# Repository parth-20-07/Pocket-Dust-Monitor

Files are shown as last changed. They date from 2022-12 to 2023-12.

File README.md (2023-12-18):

# Pocket Air Quality Index Monitor

## Why AQI Monitor is needed?
Carry Air Pocket Monitor before stepping out of your house in order to know the quality of the air you’re breathing. The pocket-sized air monitoring device is handy and easy to carry around.

It helps you understand the level of Particulate Matter 2.5 of your location. Works as both – real-time indoor and outdoor air quality monitoring sensor; the LCD display shows you PM reading indicating if the air is safe or not.

Having a desktop friendly version helps to determine the quality of air which can help you improving your life and work quality.

<br>

## Features of our AQI Monitor
- Shows the value of PM2.5 along with the safety level.
- Shows simultaneous value of PM1.0, PM2.5 and PM10.
- Plots the graph of PM2.5 on a graph in difference of 5 minutes.
- Approx. 1.5 hours Battery Backup.
- Type C charging support.

<br>

## How to assemble the project
1. Download the latest version of firmware from the /Firmware folder
2. Edit the Firmware as per the requirement with the help of guide provided in /Firmware/README.md
3. Order the components from the Bill of Materials as per the requirement.
4. Make the Hardware circuit
   1.  Solder them on General Purpose PCB Board using the design below (or)
   2.  Order the PCB by providing the PCB Developer with the gerber file available in /Hardware/PCB_Gerber.zip and solder all the component on it
5.  Upload the firmware on the the hardware

<br>

## How to use the device
1. Press the push button to turn on the device.
2. The device will start with a bootup screen with the company logo.
3. The landing page will show the value of PM 2.5 of screen.
4. Press the change screen button to switch between pages. The device works in 3 modes:
   1. Live PM 2.5 data screen.
   2. Live PM 1.0, PM 2.5, PM 10 data screen.
   3. PM 2.5 graph screen which plots the value of PM 2.5 in bar graph at an interval of 5 mins.

<center>

## Schematic Design
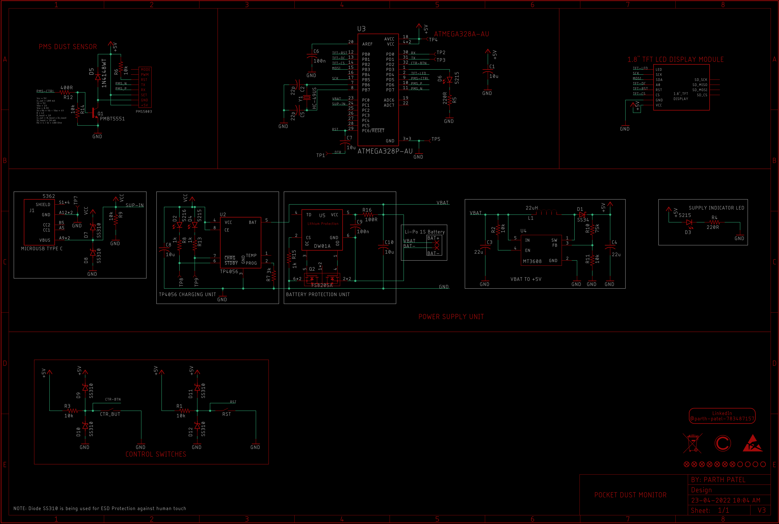
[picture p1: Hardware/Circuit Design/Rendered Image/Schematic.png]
Circuit Schematic

<br><br>

## PCB Design

Top View

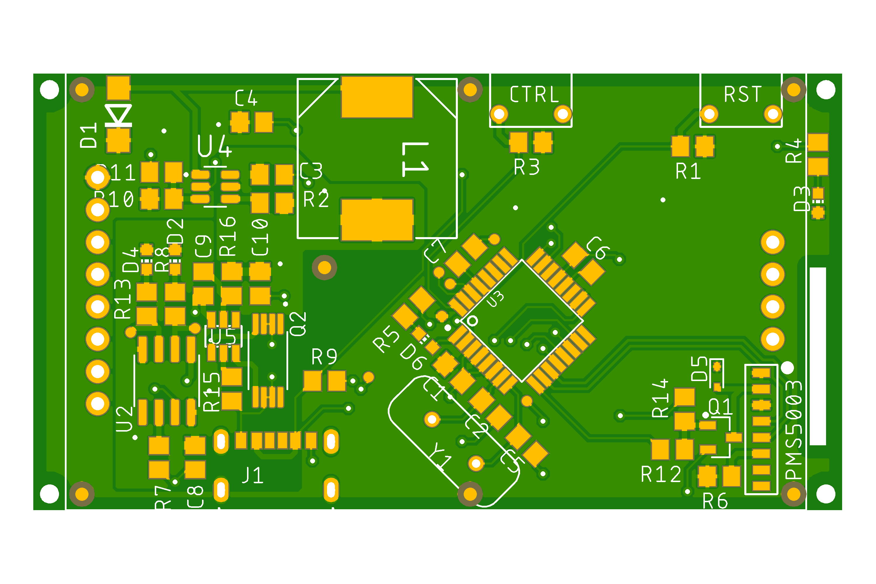
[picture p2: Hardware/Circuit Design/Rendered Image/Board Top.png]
Board Top Design


Bottom View

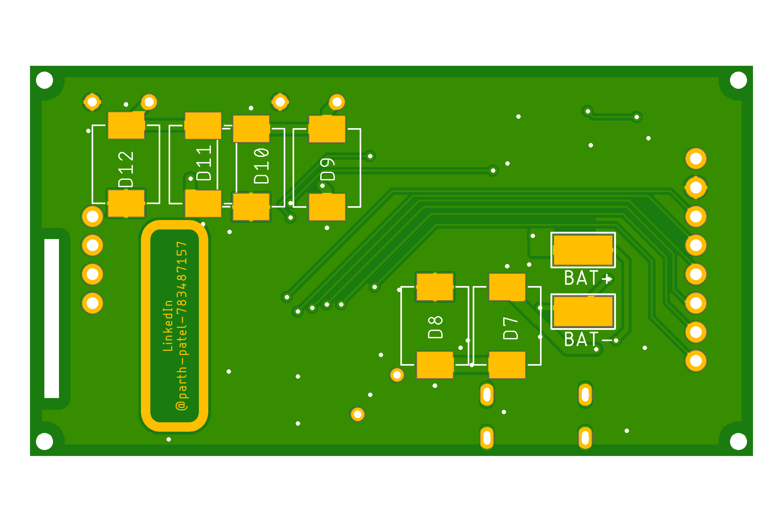
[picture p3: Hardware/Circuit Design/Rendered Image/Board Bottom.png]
Board Bottom Design


## Rendered Images

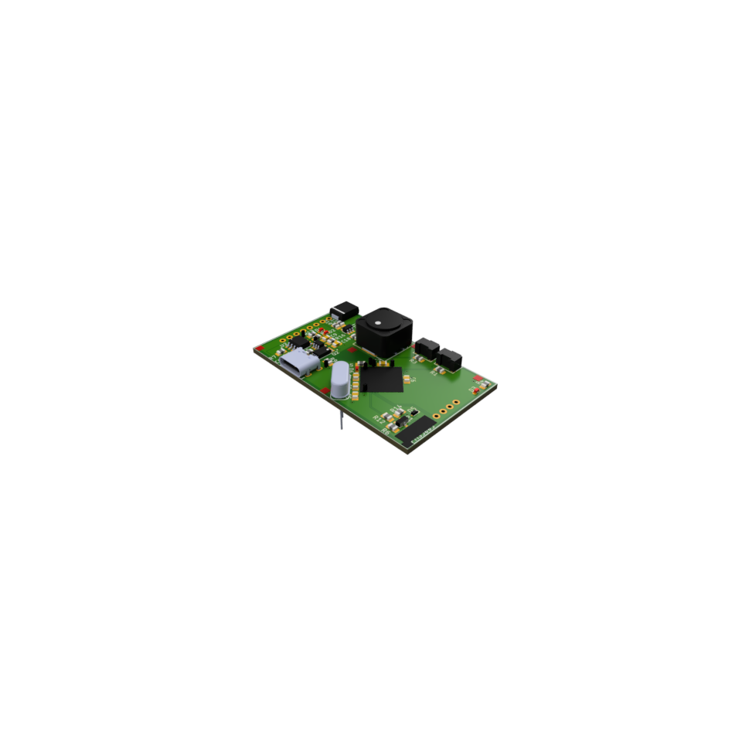
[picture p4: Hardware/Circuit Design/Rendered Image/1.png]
Rendered Design 1

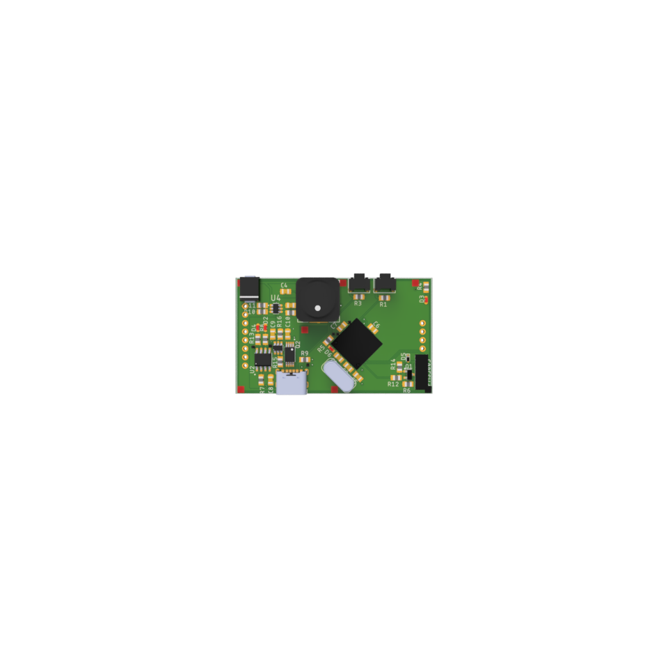
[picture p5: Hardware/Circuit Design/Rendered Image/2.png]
Rendered Design 2

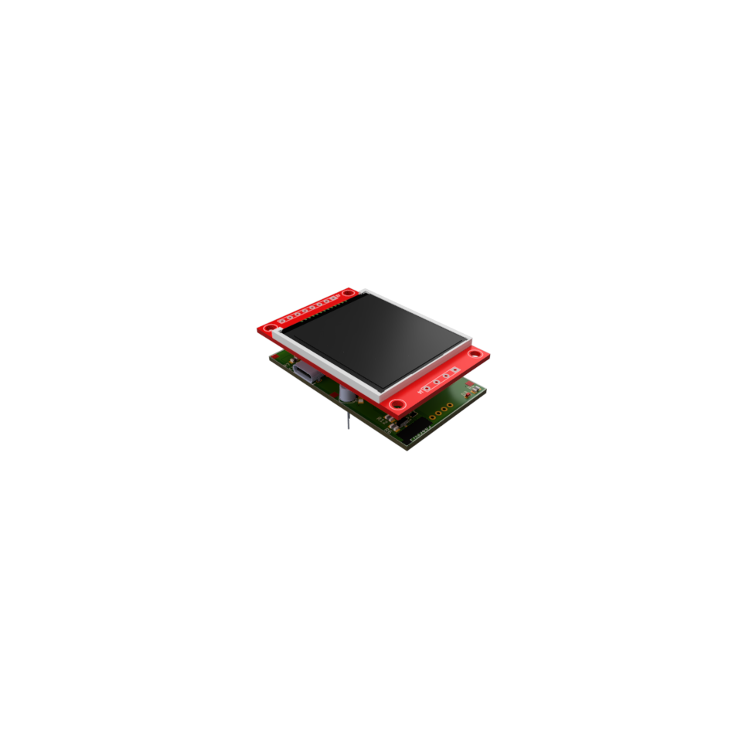
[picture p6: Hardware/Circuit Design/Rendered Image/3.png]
Rendered Design 3

</center>

## Tools Used
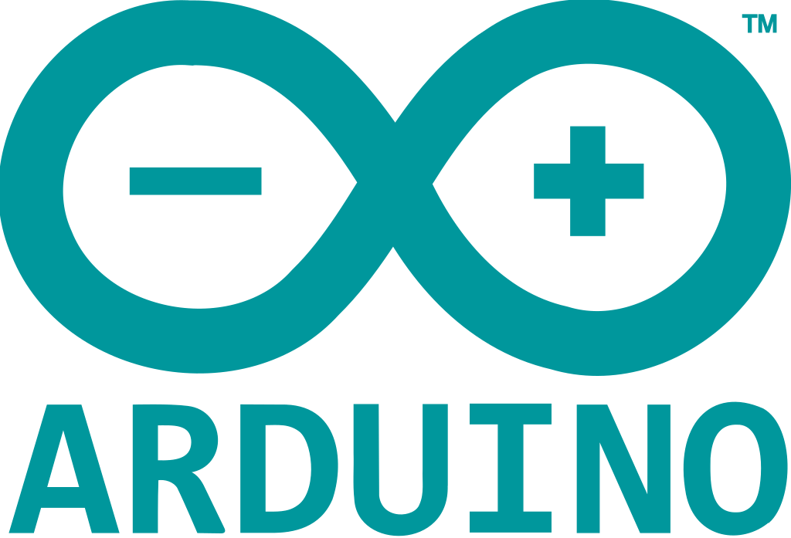
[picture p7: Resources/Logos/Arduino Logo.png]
Arduino

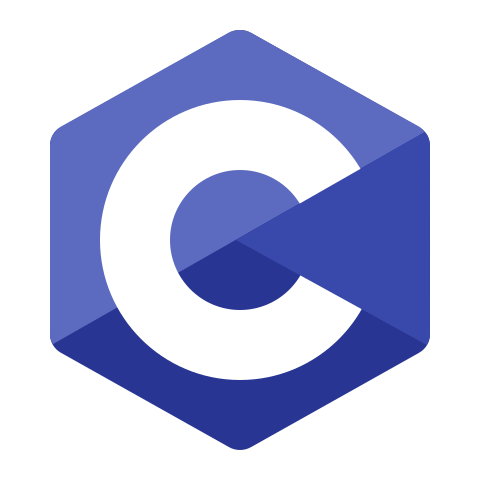
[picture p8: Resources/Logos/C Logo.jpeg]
C

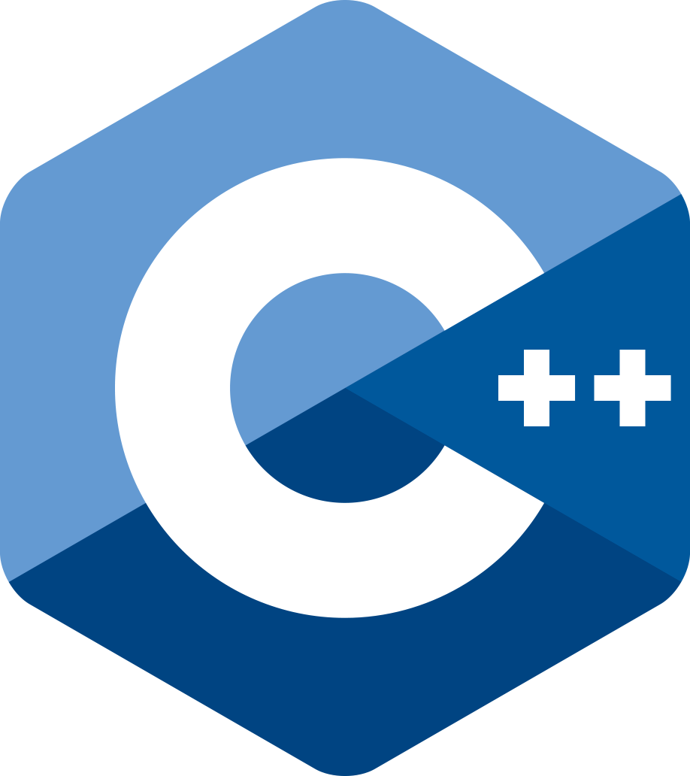
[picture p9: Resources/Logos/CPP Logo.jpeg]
CPP

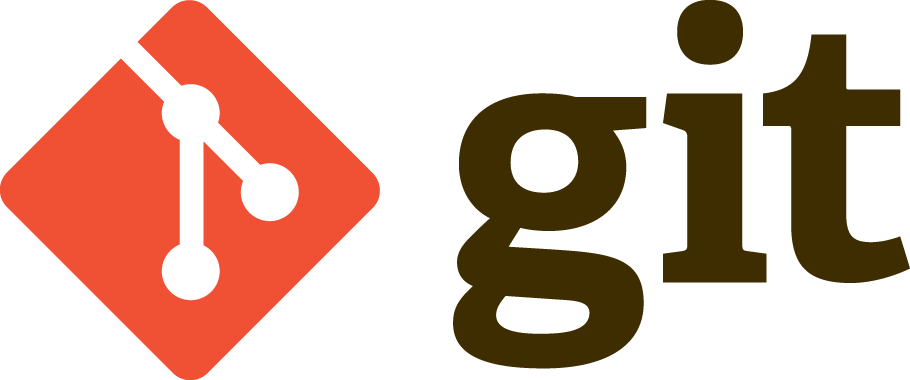
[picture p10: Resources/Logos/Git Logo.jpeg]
Git

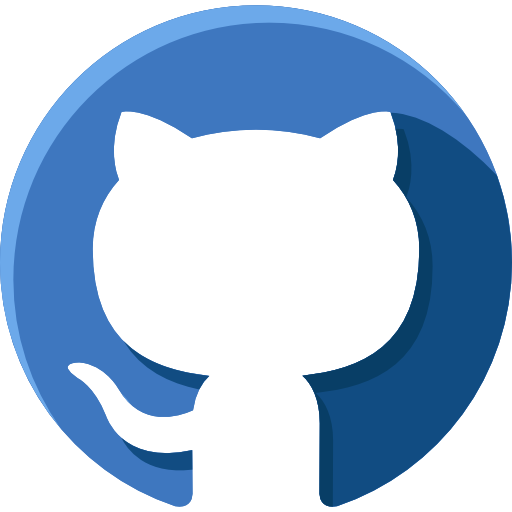
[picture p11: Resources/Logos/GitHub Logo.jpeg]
GitHub

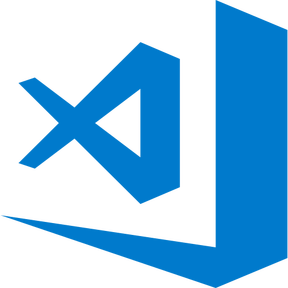
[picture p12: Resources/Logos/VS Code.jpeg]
VS Code

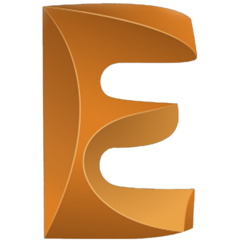
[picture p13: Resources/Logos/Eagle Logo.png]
Eagle

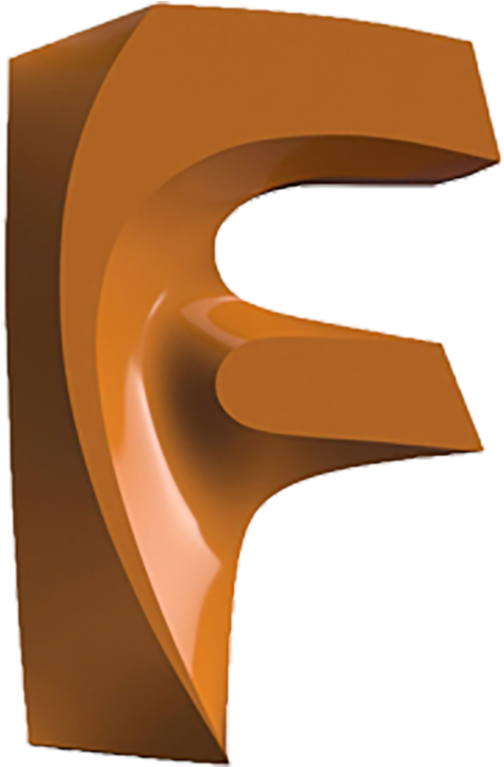
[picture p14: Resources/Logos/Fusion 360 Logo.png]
Fusion 360


<br><br>

## Design Details
- Designed for: Ecologic Pvt. Ltd.
- Designed by: [Parth Patel](mailto:parth.pmech@gmail.com)

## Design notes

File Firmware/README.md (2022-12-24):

# Firmware V2.0

### Configuration Guide for the device firmware

<br>
Modify the <Device_Configuration.h> file in the following method.

1. Under the "Sensor Connected" tab, uncomment the type of sensor connected to the device.
2. Under the "Display Connected" tab, uncomment the type of display connected.
3. If SD Support is required, uncomment the "#define SD_SUPPORT_ENABLED" under "SD Card Connected" tab.

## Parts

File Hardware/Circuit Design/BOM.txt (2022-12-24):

Partlist exported from D:/Backup Files/Files/Items/Internship/7. Ecologic/Ecologic Projects/Pocket Dust Monitor/Hardware/Circuit Design/Design.sch at 23-04-2022 01:57 PM

Qty Value           Device                    Package                     Parts                                    Description                                                                                                       AVAILABILITY BOM     DESCRIPTION                                                                                          MF                           MP                          PACKAGE                        POPULARITY PRICE PURCHASE-URL                                                   SPICEPREFIX                                                       
1   1.8"_TFT        1.8"_TFT                  1.8"_TFT                    DISPLAY                                                                                                                                                                                                                                                                                                                                                                                                                                                                                                                        
1   100R            R-US_R0805                R0805                       R16                                      RESISTOR, American symbol                                                                                                                                                                                                                                                                                                           85                                                                              R                                                                 
2   100n            C-USC0805                 C0805                       C6, C9                                   CAPACITOR, American symbol                                                                                                                                                                                                                                                                                                          63                                                                              C                                                                 
7   10k             R-US_R0805                R0805                       R1, R2, R3, R6, R9, R11, R14             RESISTOR, American symbol                                                                                                                                                                                                                                                                                                           85                                                                              R                                                                 
4   10u             C-USC0805                 C0805                       C1, C7, C8, C10                          CAPACITOR, American symbol                                                                                                                                                                                                                                                                                                          63                                                                              C                                                                 
1   1N4148WT        1N4148WT                  SODFL1608X70N               D5                                       Diode Switching 100V 0.125A 2-Pin SOD-523 Check availability                                                                                                                                                                                                                                                                                                                                                                                                                          
3   1k              R-US_R0805                R0805                       R8, R13, R15                             RESISTOR, American symbol                                                                                                                                                                                                                                                                                                           85                                                                              R                                                                 
2   220R            R-US_R0805                R0805                       R4, R5                                   RESISTOR, American symbol                                                                                                                                                                                                                                                                                                           85                                                                              R                                                                 
2   22p             C-USC0805                 C0805                       C2, C5                                   CAPACITOR, American symbol                                                                                                                                                                                                                                                                                                          63                                                                              C                                                                 
2   22u             C-USC0805                 C0805                       C3, C4                                   CAPACITOR, American symbol                                                                                                                                                                                                                                                                                                          63                                                                              C                                                                 
1   22uH            DR127-221-R               INDM125125X800N             L1                                       POWER INDUCTOR Check availability                                                                                 In Stock              Inductor Power Shielded Drum Core 221.5uH/220uH 20% 100KHz Ferrite 1.29A 376mOhm DCR T/R            Eaton                        DR127-221-R                 Nonstandard Eaton                         None  https://pricing.snapeda.com/search/part/DR127-221-R/?ref=eda                                                                     
1   3k              R-US_R0805                R0805                       R7                                       RESISTOR, American symbol                                                                                                                                                                                                                                                                                                           85                                                                              R                                                                 
1   400R            R-US_R0805                R0805                       R12                                      RESISTOR, American symbol                                                                                                                                                                                                                                                                                                           85                                                                              R                                                                 
3   5215            LEDCHIP-LED0603           CHIP-LED0603                D3, D4, D6                               LED                                                                                                                                                                                                                                                                                                                                 26                                                                                                                                                
1   5216            LEDCHIP-LED0603           CHIP-LED0603                D2                                       LED                                                                                                                                                                                                                                                                                                                                 26                                                                                                                                                
1   5362            6_PIN_TYPE_C_FEMALE       GCT_USB4125-GF-A-0190_REVA2 J1                                       Check availability                                                                                                In Stock              USB-C (USB TYPE-C) USB 2.0 Receptacle Connector 24 (6+18 Dummy) Position Surface Mount, Right Angle  Through Hole                Global Connector Technology USB4125-GF-A-0190              None             None                                                           https://pricing.snapeda.com/search/part/USB4125-GF-A-0190/?ref=eda
2   7058            DIP_3X6MM_SIDE_PRESS_2PIN DIP_3X6MM_SIDE_PRESS_2PIN   CTR_BUT, RST                                                                                                                                                                                                                                                                                                                                                                                                                                                                                                                   
1   75k             R-US_R0805                R0805                       R10                                      RESISTOR, American symbol                                                                                                                                                                                                                                                                                                           85                                                                              R                                                                 
1   ATMEGA328P-AU   ATMEGA328P-AU             QFP80P900X900X120-32N       U3                                       ATmega Series 20 MHz 32 KB Flash 2 KB SRAM 8-Bit Microcontroller - TQFP-32 Check availability                     In Stock              AVR AVR® ATmega Microcontroller IC 8-Bit 20MHz 32KB (16K x 16) FLASH 32-TQFP (7x7)                  Microchip Technology         ATMEGA328P-AU               TQFP-32 Microchip                         None  https://pricing.snapeda.com/search/part/ATMEGA328P-AU/?ref=eda                                                                   
1   DW01A           DW01A                     SOT23-6                     U5                                       Check availability                                                                                                Not in stock          One Cell Lithium-ion/Polymer Battery Protection IC                                                  Fortune Semiconductor        DW01A                       SOT-23-6 Fortune Semiconductor            None                                                                                                                                   
1   FS8205A         FS8205A                   SOP65P640X120-8N            Q2                                       N/A Check availability                                                                                            Not in stock                                                                                                              Fortune Semiconductor        FS8205A                     Package                                   None                                                                                                                                   
1   HC-49US         ECS-160-20-4X             XTAL_ECS-160-20-4X          Y1                                       CRYSTAL T/H Check availability                                                                                    In Stock              16 MHz ±30ppm Crystal 20pF 40 Ohms HC-49/US                                                         ECS Inc.                     ECS-160-20-4X               HC-49US ECS Inc.                          None  https://pricing.snapeda.com/search/part/ECS-160-20-4X/?ref=eda                                                                   
1   MT3608          MT3608                    SOT95P280X145-6N            U4                                       High Efficiency 1.2MHz 2A Step Up Converter Check availability                                                    Not in stock          High Efficiency 1.2MHz 2A Step Up Converter                                                         Aerosemi Technology Co., Ltd MT3608                      Package                                   None                                                                                                                                   
1   PMBT5551        PMBT5551                  SOT95P240X110-3N            Q1                                       AAL Eindhoven MK                                                                                                                                                                                                                                                                                                                                                                                                                                                                      
1   PMS5003         PMS5003                   PMS5003                     PMS5003                                                                                                                                                                                                                                                                                                                                                                                                                                                                                                                        
6   SS310           SS310                     DIOM6859X262N               D7, D8, D9, D10, D11, D12                Check availability                                                                                                In Stock              3A, 100V, Schottky Rectifier                                                                        Taiwan Semiconductor         SS310                       SMC-2 Taiwan Semiconductor                None  https://pricing.snapeda.com/search/part/SS310/?ref=eda                                                                           
1   SS34            SS34                      DO214                       D1                                       SS34 Schottky diode                                                                                               In Stock              Diode Schottky 40 V 3A Surface Mount SMC (DO-214AB)                                                 ON Semiconductor             SS34                        SMC-2 ON Semiconductor                    None  https://pricing.snapeda.com/search/part/SS34/?ref=eda                                                                            
1   TP4056          TP4056                    SOP127P600X175-9N           U2                                       Complete single cell Li-Ion battery with a constant current / constant voltage linear charger  Check availability Not in stock          Complete single cell Li-Ion battery with a constant current / constant voltage linear charger       NanJing Top Power ASIC Corp. TP4056                      None                                      None

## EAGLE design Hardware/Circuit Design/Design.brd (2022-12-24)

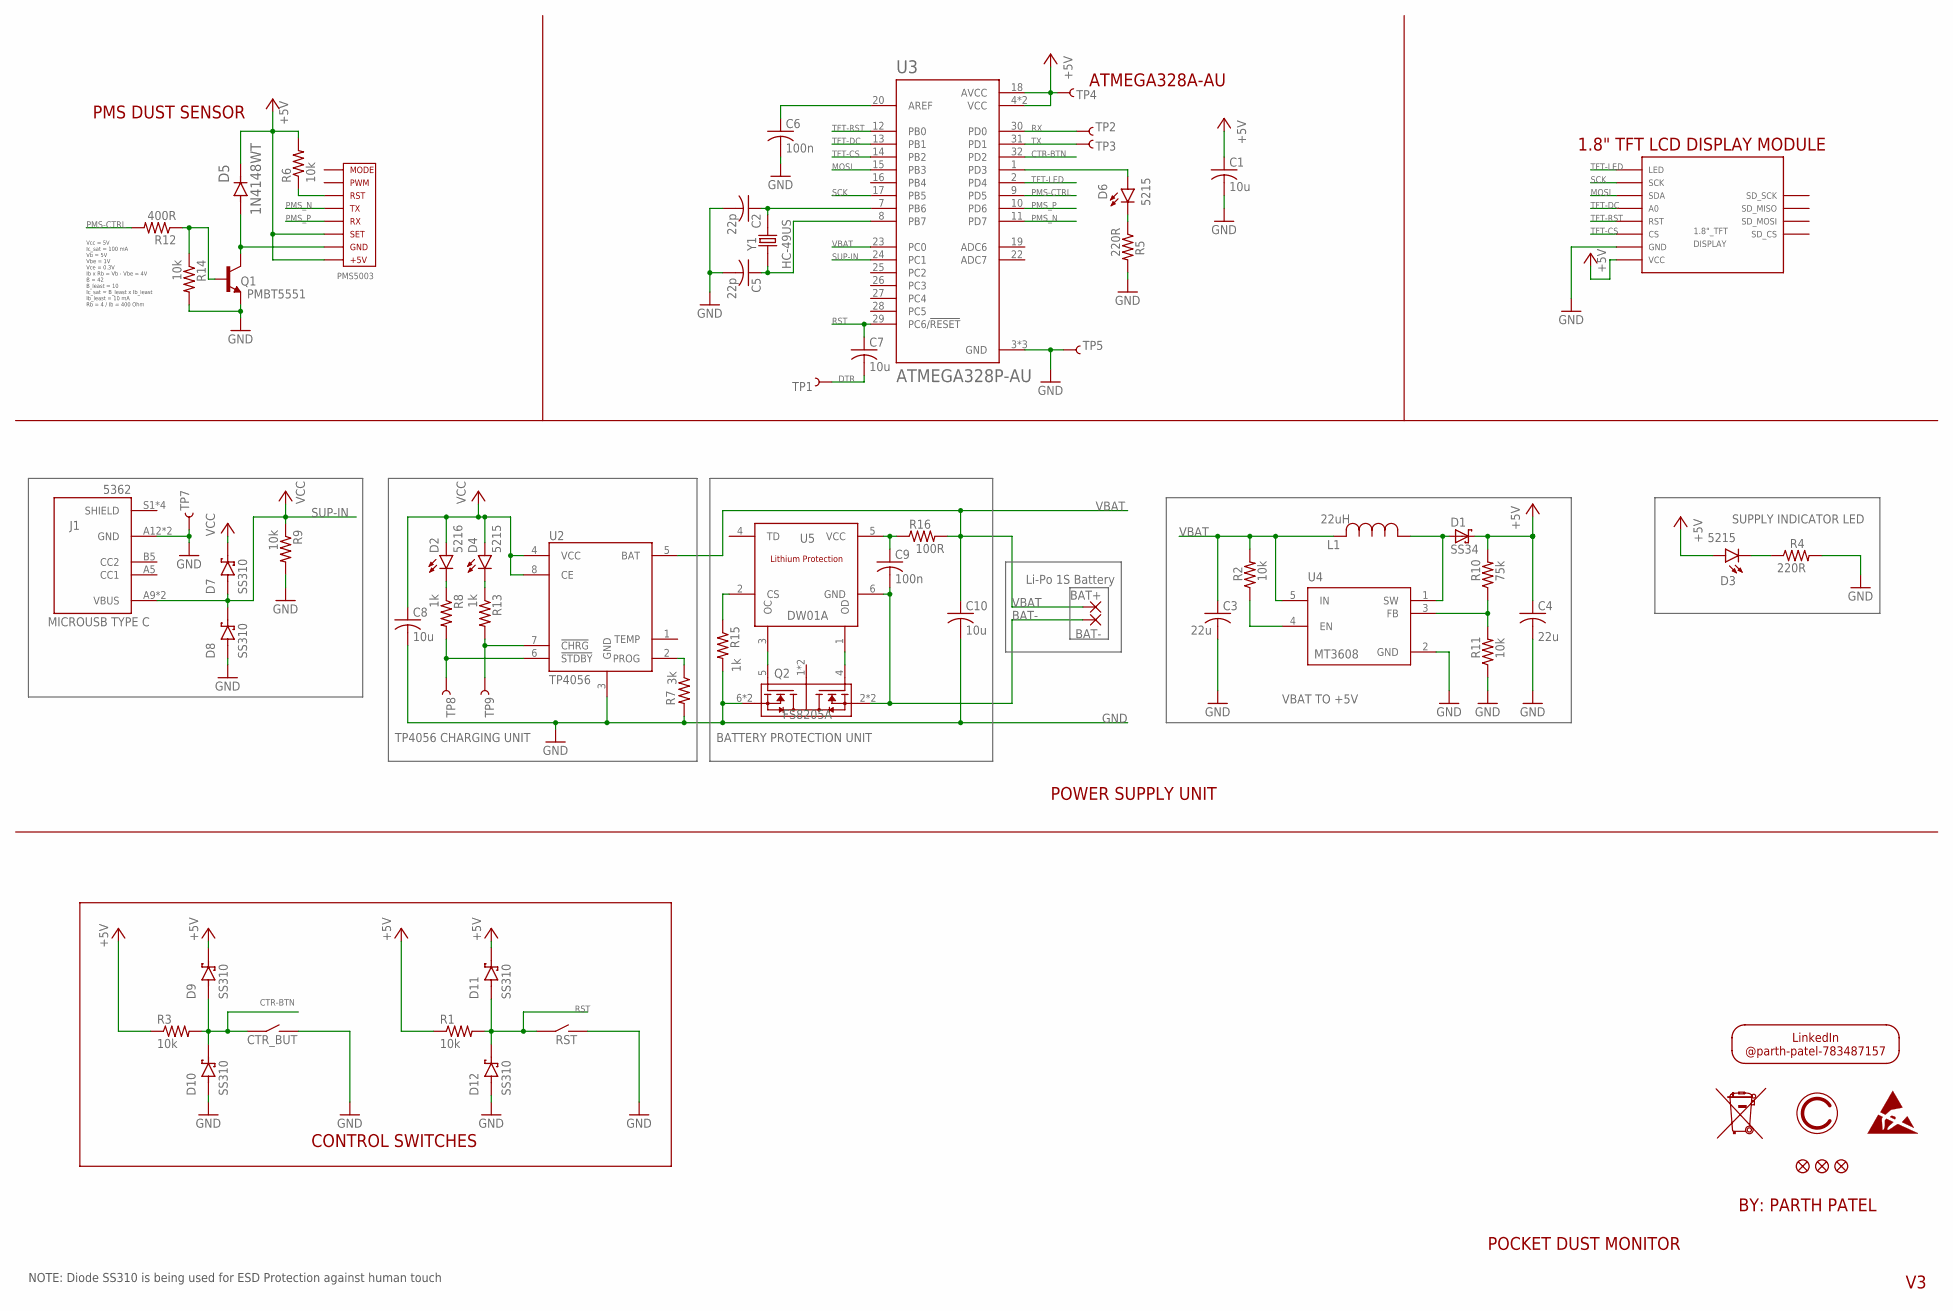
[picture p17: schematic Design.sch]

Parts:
BAT+: WIREPADSMD5-2,5; 5-2,5
BAT-: WIREPADSMD5-2,5; 5-2,5
C1, C7, C8, C10: 10u; C0805
C2, C5: 22p; C0805
C3, C4: 22u; C0805
C6, C9: 100n; C0805
CTR_BUT: 7058; DIP_3X6MM_SIDE_PRESS_2PIN
D1: SS34; DO214
D2: 5216; CHIP-LED0603
D3, D4, D6: 5215; CHIP-LED0603
D5: 1N4148WT; SODFL1608X70N
D7, D8, D9, D10, D11, D12: SS310; DIOM6859X262N
DISPLAY: 1.8"_TFT
FID3, FID4, FID5: FIDUCIAL""; FIDUCIAL_1MM
J1: 5362; GCT_USB4125-GF-A-0190_REVA2
L1: 22uH; INDM125125X800N
PMS5003: PMS5003
Q1: PMBT5551; SOT95P240X110-3N
Q2: FS8205A; SOP65P640X120-8N
R1, R2, R3, R6, R9, R11, R14: 10k; R0805
R4, R5: 220R; R0805
R7: 3k; R0805
R8, R13, R15: 1k; R0805
R10: 75k; R0805
R12: 400R; R0805
R16: 100R; R0805
RST: 7058; DIP_3X6MM_SIDE_PRESS_2PIN
TP1, TP2, TP3, TP4, TP5, TP7: TEST-POINT3; PAD.03X.03
TP8: ~STDBY; PAD.03X.03
TP9: ~CHRG; PAD.03X.03
U2: TP4056; SOP127P600X175-9N
U3: ATMEGA328P-AU; QFP80P900X900X120-32N
U4: MT3608; SOT95P280X145-6N
U5: DW01A; SOT23-6
U$1: LOGO_17MM; FOOTPRINT_17MM
Y1: HC-49US; XTAL_ECS-160-20-4X

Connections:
+5V: C1.1, C4.1, D1.C, D3.A, D5.D+, D9.C (K), D11.C (K), DISPLAY.VCC (+5V), PMS5003.+5V, PMS5003.SET, R1.1, R3.1, R6.2, R10.2, TP4.P$1, U3.4 (VCC), U3.6 (VCC), U3.18 (AVCC)
BAT-: BAT-.1, C9.2, Q2.2 (S1), Q2.3 (S1), U5.6 (GND)
CTR-BTN: CTR_BUT.P$1 (S1), D9.A, D10.C (K), R3.2, U3.32 (PD2)
DTR: C7.2, TP1.P$1
GND: C1.2, C2.2, C3.2, C4.2, C5.2, C6.2, C8.2, C10.2, CTR_BUT.P$2 (S2), D8.A, D10.A, D12.A, DISPLAY.GND, J1.A12 (GND), J1.B12 (GND), Q1.E, Q2.6 (S2), Q2.7 (S2), R4.2, R5.2, R7.2, R9.2, R11.1, R14.2, R15.2, RST.P$2 (S2), TP5.P$1, TP7.P$1, U2.3 (GND), U3.3 (GND), U3.5 (GND), U3.21 (GND), U4.2 (GND)
MOSI: DISPLAY.SDA, U3.15 (PB3)
unnamed: D5.D-, PMS5003.GND, Q1.C
unnamed: C5.1, U3.8 (PB7), Y1.1
unnamed: D3.C, R4.1
unnamed: Q1.B, R12.1, R14.1
unnamed: R2.1, U4.4 (EN)
unnamed: C6.1, U3.20 (AREF)
unnamed: PMS5003.RST, R6.1
unnamed: D4.C, R13.1
unnamed: D2.C, R8.1
unnamed: C2.1, U3.7 (PB6), Y1.2
unnamed: D1.A, L1.1, U4.1 (SW)
unnamed: R10.1, R11.2, U4.3 (FB)
unnamed: D6.C, R5.1
unnamed: D6.A, U3.1 (PD3)
unnamed: Q2.5 (G2), U5.3 (OC)
unnamed: R13.2, TP9.P$1, U2.7 (!CHRG)
unnamed: R8.2, TP8.P$1, U2.6 (!STDBY)
unnamed: R7.1, U2.2 (PROG)
unnamed: Q2.4 (G1), U5.1 (OD)
unnamed: R15.1, U5.2 (CS)
unnamed: C9.1, R16.1, U5.5 (VCC)
PMS-CTRL: R12.2, U3.9 (PD5)
PMS_N: PMS5003.TX, U3.11 (PD7)
PMS_P: PMS5003.RX, U3.10 (PD6)
RST: C7.1, D11.A, D12.C (K), R1.2, RST.P$1 (S1), U3.29 (PC6/!RESET)
RX: TP2.P$1, U3.30 (PD0)
SCK: DISPLAY.SCK, U3.17 (PB5)
SUP-IN: D7.A, D8.C (K), J1.A9 (VBUS), J1.B9 (VBUS), R9.1, U3.24 (PC1)
TFT-CS: DISPLAY.CS, U3.14 (PB2)
TFT-DC: DISPLAY.DC (A0), U3.13 (PB1)
TFT-LED: DISPLAY.LED, U3.2 (PD4)
TFT-RST: DISPLAY.RST, U3.12 (PB0)
TX: TP3.P$1, U3.31 (PD1)
VBAT: BAT+.1, C3.1, C10.1, L1.2, R2.2, R16.2, U2.5 (BAT), U3.23 (PC0), U4.5 (IN)
VCC: C8.1, D2.A, D4.A, D7.C (K), U2.4 (VCC), U2.8 (CE)

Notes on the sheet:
POWER SUPPLY UNIT
POCKET DUST MONITOR
BY: PARTH PATEL
CONTROL SWITCHES
PMS DUST SENSOR
PMS5003
ATMEGA328A-AU
1.8" TFT LCD DISPLAY MODULE
MICROUSB TYPE C
VBAT TO +5V
TP4056 CHARGING UNIT
Vcc = 5V Ic_sat = 100 mA Vb = 5V Vbe = 1V Vce = 0.3V Ib x Rb = Vb - Vbe = 4V B = 42 B_least = 10 Ic_sat = B_least x Ib_least Ib_least = 10 mA Rb = 4 / Ib = 400 Ohm
Li-Po 1S Battery
BATTERY PROTECTION UNIT
SUPPLY INDICATOR LED
NOTE: Diode SS310 is being used for ESD Protection against human touch

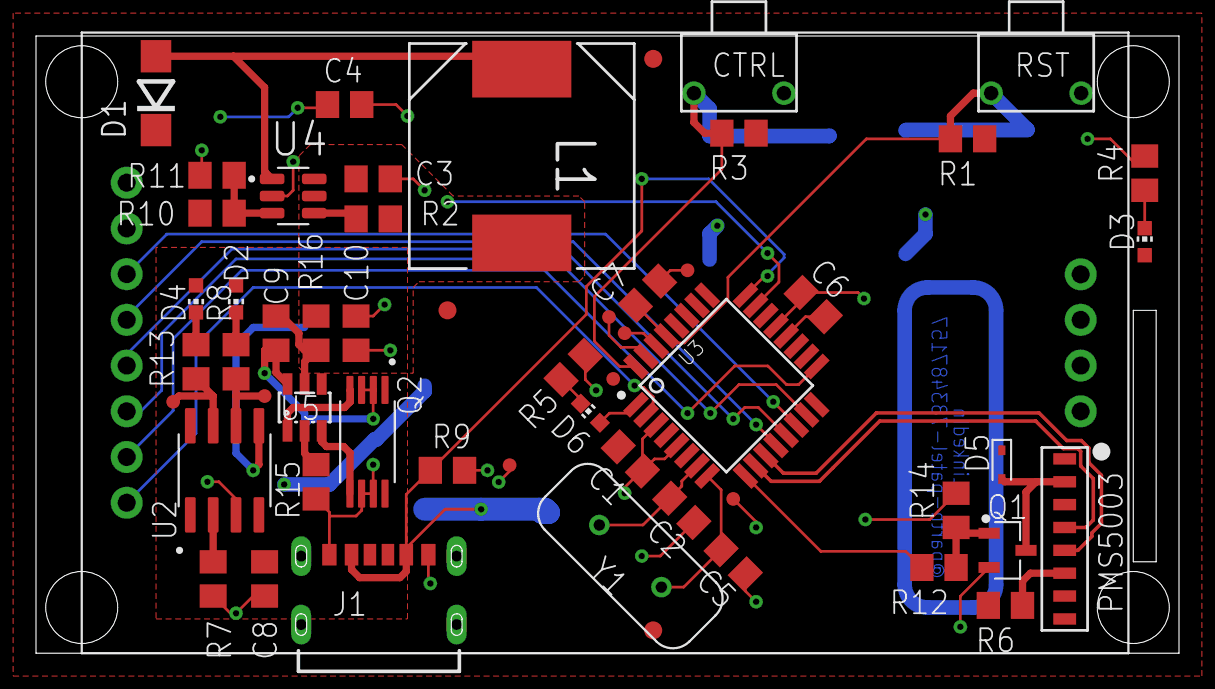
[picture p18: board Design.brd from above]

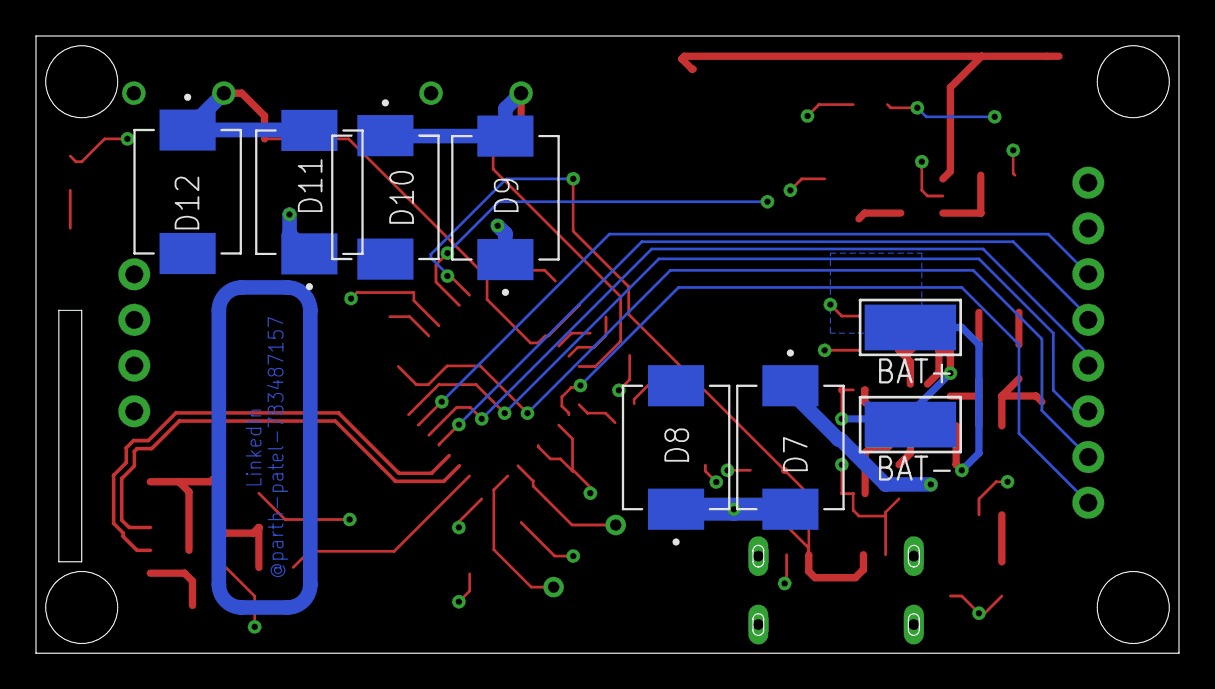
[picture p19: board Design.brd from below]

Board: 2 copper layers, 63.5 x 34.3 mm, 65 parts (9 on the bottom side), 41 nets.

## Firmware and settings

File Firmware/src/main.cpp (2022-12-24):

/**
 * @file main.cpp
 * @author Parth Patel (parth.pmech@gmail.com)
 * @brief
 * @version 0.1
 * @date 2021-12-05
 * @copyright Copyright (c) 2021
 * ! DO NOT CHANGE
 */

//!=============================== BASIC DECLARATION ===============================//
#include <Arduino.h>
#include "Pin_Connection.h"
#include "Variable_Declaration.h"
#include "Sensor_Data_Collection.cpp"
#include <avr/sleep.h>
//!==================================================================================//

//!============================== FUNCTION DEFINITION ==============================//
void boot_screen(void);
void graphic_data_screen(void);
void drawing_battery(void);
void three_point_data_screen(void);
void draw_graph_screen(void);
void plot_graph_bar(void);
void changing_screen_display(void);
void change_screen(void);
void start_device_peripherals(void);
void shutdown_device_peripherals(void);
//!==================================================================================//

//!============================== FUNCTION DECLARATION ==============================//

/**
 * @brief Print the Boot Screen on the device startup
 */
void boot_screen(void)
{
  Serial.println("Printing Boot Screen");
  Serial.println("Drawing LOGO");
  screen.background(BLACK_COLOR);
  screen.setTextSize(2);
  screen.stroke(WHITE_COLOR);
  screen.text("ECOLOGIC", 20, (screen_height / 2) - 10);
  delay(5000);
}

/**
 * @brief Draws the bubble screen for displaying the PM 2.5 Value on the screen
 */
void graphic_data_screen(void)
{
  changing_screen_display();
  change_screen_flag = false;
  Serial.println("Drawing Graphic Screen");
  uint16_t registered_level = 0;
  collect_dust_quality_data();
  screen.background(BLACK_COLOR);
  // Design variable declaration
  double indicator_height = 4;
  double indicator_bar_width = screen_width - 4;
  double green_indicator = (MAX_SAFETY_LIMIT * indicator_bar_width) / MAX_HAZARDOUS_LIMIT;
  double warning_indicator = ((MAX_WARNING_LIMIT - MAX_SAFETY_LIMIT) * indicator_bar_width) / MAX_HAZARDOUS_LIMIT;
  double severe_indicator = ((MAX_UNHEALTHY_LIMIT - MAX_WARNING_LIMIT) * indicator_bar_width) / MAX_HAZARDOUS_LIMIT;
  double danger_indicator = ((MAX_HAZARDOUS_LIMIT - MAX_UNHEALTHY_LIMIT) * indicator_bar_width) / MAX_HAZARDOUS_LIMIT;
  uint8_t indicator_x_starting_pos = 2;
  uint8_t indicator_y_starting_pos = (screen_height / 2) + 32;
  uint8_t green_indicator_height = (uint8_t)green_indicator;
  uint8_t warning_indicator_height = (uint8_t)warning_indicator;
  uint8_t severe_indicator_height = (uint8_t)severe_indicator;
  uint8_t danger_indicator_height = (uint8_t)danger_indicator;
  uint8_t seperation_line_height = 25;

  // Drawing seperation line
  screen.stroke(GREY_COLOR);
  screen.line(0, seperation_line_height, (screen_width / 2) - 30, seperation_line_height);
  screen.setTextSize(1);
  screen.text("PM2.5", (screen_width / 2) - 10, seperation_line_height - 3);
  screen.line((screen_width / 2) + 30, seperation_line_height, screen_width, seperation_line_height);

  // Drawing the indicator Bar
  screen.stroke(GREEN_COLOR);
  screen.fill(GREEN_COLOR);
  screen.rect(indicator_x_starting_pos, indicator_y_starting_pos, green_indicator_height, indicator_height);
  screen.stroke(YELLOW_COLOR);
  screen.fill(YELLOW_COLOR);
  screen.rect(indicator_x_starting_pos + green_indicator_height, indicator_y_starting_pos, warning_indicator_height, indicator_height);
  screen.stroke(ORANGE_COLOR);
  screen.fill(ORANGE_COLOR);
  screen.rect(indicator_x_starting_pos + green_indicator_height + warning_indicator_height, indicator_y_starting_pos, severe_indicator_height, indicator_height);
  screen.stroke(RED_COLOR);
  screen.fill(RED_COLOR);
  screen.rect(indicator_x_starting_pos + green_indicator_height + warning_indicator_height + severe_indicator_height, indicator_y_starting_pos, danger_indicator_height, indicator_height);
  last_millis = millis();
  bool first_time = true;
  while (1)
  {
    if ((digitalRead(INT_PIN) == LOW) || change_screen_flag)
    {
      change_screen();
      break;
    }

    // Calculating values for the design
    int arrow_x_position = 0;
    if (registered_level < MAX_HAZARDOUS_LIMIT)
      arrow_x_position = indicator_x_starting_pos + (registered_level * indicator_bar_width / MAX_HAZARDOUS_LIMIT);
    else
      arrow_x_position = indicator_x_starting_pos + indicator_bar_width;
    int arrow_y_position = indicator_y_starting_pos - 5;

    if (((registered_level > 0) && ((millis() - last_millis) > SCREEN_REFRESH_TIME)) || (first_time))
    {
      Serial.println("Registered Level: " + (String)registered_level);
      first_time = false;
      drawing_battery(); // Drawing Header: Company Name and Battery Percentage
      screen.noStroke();

      // Clearing the older values
      screen.stroke(BLACK_COLOR);
      screen.fill(BLACK_COLOR);
      screen.rect(0, arrow_y_position - 9, screen_width, 10);
      screen.rect(0, indicator_y_starting_pos + indicator_height + 5, screen_width, 15);

      // Drawing The circle with latest values
      if (registered_level < MAX_SAFETY_LIMIT)
      {
        screen.stroke(GREEN_COLOR);
        screen.fill(GREEN_COLOR);
        screen.text("SAFE", indicator_x_starting_pos, indicator_y_starting_pos + indicator_height + 5);
      }
      else if (registered_level < MAX_WARNING_LIMIT)
      {
        screen.stroke(YELLOW_COLOR);
        screen.fill(YELLOW_COLOR);
        screen.text("MODERATE", indicator_x_starting_pos, indicator_y_starting_pos + indicator_height + 5);
      }
      else if (registered_level < MAX_UNHEALTHY_LIMIT)
      {
        screen.stroke(ORANGE_COLOR);
        screen.fill(ORANGE_COLOR);
        screen.text("UNHEALTHY", indicator_x_starting_pos, indicator_y_starting_pos + indicator_height + 5);
      }
      else
      {
        screen.stroke(RED_COLOR);
        screen.fill(RED_COLOR);
        screen.text("HAZARDOUS", indicator_x_starting_pos, indicator_y_starting_pos + indicator_height + 5);
      }
      screen.circle(screen_width / 2, (screen_height / 2) - 15, screen_width / 4);

      // Draw the indicator arrow
      screen.line(arrow_x_position, arrow_y_position, arrow_x_position - 4, arrow_y_position - 8);
      screen.line(arrow_x_position, arrow_y_position, arrow_x_position + 4, arrow_y_position - 8);
      screen.line(arrow_x_position - 4, arrow_y_position - 8, arrow_x_position + 4, arrow_y_position - 8);

      // Writing the text on the circle
      screen.setTextSize(3);
      screen.stroke(BLACK_COLOR);
      screen.text(pm_ae_2_5, (screen_width / 2) - 20, (screen_height / 2) - 25);
      screen.setTextSize(1);
      screen.text("ug/m", (screen_width / 2) - 10, (screen_height / 2) + 5);
      screen.text("3", (screen_width / 2) + 13, (screen_height / 2) + 2);
      last_millis = millis();
    }
    collect_dust_quality_data();
    registered_level = atoi(pm_ae_2_5);
  }
}

/**
 * @brief Draws the battery level after measuring the battery level on the screen in upper right corner of screen when called.
 */
void drawing_battery(void)
{
  // Writing Company Logo
  screen.stroke(WHITE_COLOR);
  screen.setTextSize(2);
  screen.text(company_name, 2, MARGIN_BUFFER);

  int xStart = screen_width - BATTERY_SYMBOL_WIDTH - MARGIN_BUFFER;
  int yStart = MARGIN_BUFFER;
  // Clearing previous battery value
  screen.noStroke();
  screen.fill(BLACK_COLOR);
  screen.rect(xStart, yStart, BATTERY_SYMBOL_WIDTH, BATTERY_SYMBOL_HEIGHT);
  // Creating battery Outline
  screen.stroke(WHITE_COLOR);
  screen.rect(xStart, yStart, BATTERY_SYMBOL_WIDTH, BATTERY_SYMBOL_HEIGHT);
  screen.fill(WHITE_COLOR);
  screen.rect(xStart + BATTERY_SYMBOL_WIDTH, yStart + MARGIN_BUFFER, MARGIN_BUFFER, (BATTERY_SYMBOL_HEIGHT - (2 * MARGIN_BUFFER)));

  // Creating Battery Fill
  float val1 = (analogRead(BATTERY_INPUT) - MIN_BATTERY_ADC_VALUE);
  float available_battery_percentage = (val1 * 100) / MAX_BATTERY_ADC_VALUE;
  // Serial.println("Raw Battery Analog value:" + (String)analogRead(BATTERY_INPUT));
  Serial.println("Battery Level: " + (String)available_battery_percentage + "%");
  float bat_bar_width = (available_battery_percentage * BATTERY_SYMBOL_WIDTH) / 100;
  int battery_bar_width = bat_bar_width;
  // Serial.println("Integer Bar Width:" + (String)battery_bar_width);
  screen.noStroke();

  if (available_battery_percentage < LOW_BATTERY_PERCENT)
    screen.fill(RED_COLOR);
  else if (available_battery_percentage < MEDIUM_BATTERY_PERCENT)
    screen.fill(ORANGE_COLOR);
  else
    screen.fill(GREEN_COLOR);
  screen.rect(xStart + 1, yStart + 1, battery_bar_width - 2, BATTERY_SYMBOL_HEIGHT - 2);
  if (digitalRead(CONNECTED_SUPPLY_PIN))
  {
    Serial.println("Charger Connected");
    int batxStart = screen_width - (BATTERY_SYMBOL_WIDTH / 2) - MARGIN_BUFFER;
    int batyStart = MARGIN_BUFFER + 1;
    int bat_symbol_width = 2;
    screen.stroke(WHITE_COLOR);
    screen.line(batxStart, batyStart, batxStart - bat_symbol_width, batyStart + (BATTERY_SYMBOL_HEIGHT / 2));
    screen.line(batxStart - bat_symbol_width, batyStart + (BATTERY_SYMBOL_HEIGHT / 2) - 1, batxStart + bat_symbol_width, batyStart + (BATTERY_SYMBOL_HEIGHT / 2) - 1);
    screen.line(batxStart + bat_symbol_width, batyStart + (BATTERY_SYMBOL_HEIGHT / 2) - 1, batxStart, batyStart + BATTERY_SYMBOL_HEIGHT - 2);
    screen.line(batxStart, batyStart + BATTERY_SYMBOL_HEIGHT - 2, batxStart, batyStart);
  }
}

/**
 * @brief Draws the screen and the values of PMS 1.0, PM 2.5 and PM 10.0 together on a single screen in a grid manner
 */
void three_point_data_screen(void)
{
  changing_screen_display();
  change_screen_flag = false;
  Serial.println("Drawing 3 Data Monitor Screen");
  collect_dust_quality_data();

  screen.background(BLACK_COLOR);

  // Drawing the layout
  drawing_battery();
  int seperation_line_height = 25;
  screen.stroke(GREY_COLOR);
  screen.line(0, seperation_line_height, screen_width, seperation_line_height);
  screen.line(screen_width / 2, seperation_line_height, screen_width / 2, screen_height);
  screen.line(screen_width / 2, (screen_height + seperation_line_height) / 2, screen_width, (screen_height + seperation_line_height) / 2);
  screen.stroke(ORANGE_COLOR);
  screen.setTextSize(1);
  screen.text("PM1.0", (3 * screen_width / 4) - 10, seperation_line_height + 5);
  screen.text("PM10", (3 * screen_width / 4) - 10, ((screen_height + seperation_line_height) / 2) + 5);
  screen.text("ug/m", (screen_width / 4) - 15, screen_height - 10);
  screen.text("3", (screen_width / 4) + 10, screen_height - 15);
  screen.setTextSize(2);
  screen.text("PM2.5", (screen_width / 4) - 27, seperation_line_height + 5);
  int text_seperation_height = 45;

  // Writing the data
  bool first_time = true;
  last_millis = millis();
  Serial.println("Starting Unit");
  while (1)
  {
    if ((digitalRead(INT_PIN) == LOW) || change_screen_flag)
    {
      change_screen();
      break;
    }

    while (((millis() - last_millis) > SCREEN_REFRESH_TIME) || (first_time))
    {
      first_time = false;

      if (atoi(pm_ae_1_0) > 0)
      {
        Serial.println("PM AE 1.0: " + String(atoi(pm_ae_1_0)));
        Serial.println("PM AE 2.5: " + String(atoi(pm_ae_2_5)));
        Serial.println("PM AE 10: " + String(atoi(pm_ae_10_0)));
        Serial.println();
        drawing_battery();
        // Cleaning Previous Values
        screen.noStroke();
        screen.fill(BLACK_COLOR);
        screen.rect((screen_width / 4) - 30, text_seperation_height + 25, 60, 30);
        screen.rect((3 * screen_width / 4) - 25, ((screen_height + text_seperation_height) / 2) + 5, 60, 30);
        screen.rect((3 * screen_width / 4) - 25, text_seperation_height - 5, 60, 30);

        // Writing New Values
        screen.setTextSize(3);
        screen.stroke(YELLOW_COLOR);
        screen.text(pm_ae_2_5, (screen_width / 4) - 25, text_seperation_height + 30);
        screen.text(pm_ae_10_0, (3 * screen_width / 4) - 20, ((screen_height + text_seperation_height) / 2) + 10);
        screen.stroke(PINK_COLOR);
        screen.text(pm_ae_1_0, (3 * screen_width / 4) - 20, text_seperation_height);
        last_millis = millis();
      }
      Serial.println();
      collect_dust_quality_data();
    }
  }
}

/**
 * @brief Draws the background to plot the values of PM 2.5
 */
void draw_graph_screen(void)
{
  Serial.println("Draw Graph Background");
  collect_dust_quality_data();

  screen.background(BLACK_COLOR);
  screen.stroke(GREY_COLOR);
  screen.line(GRAPH_BUFFER_SCREEN, GRAPH_BUFFER_SCREEN, GRAPH_BUFFER_SCREEN, screen_height - GRAPH_BUFFER_SCREEN);
  screen.line(GRAPH_BUFFER_SCREEN, screen_height - GRAPH_BUFFER_SCREEN, screen_width - GRAPH_BUFFER_SCREEN, screen_height - GRAPH_BUFFER_SCREEN);
  int x_dots = ((screen_width - (2 * GRAPH_BUFFER_SCREEN)) / GRAPH_BUFFER_SCREEN + 1);
  int y_dots = ((screen_height - (2 * GRAPH_BUFFER_SCREEN)) / GRAPH_BUFFER_SCREEN) + 1;
  for (size_t i = 0; i < y_dots; i++)
    for (size_t j = 0; j < x_dots; j++)
      screen.point((j * GRAPH_BUFFER_SCREEN) + GRAPH_BUFFER_SCREEN, (i * GRAPH_BUFFER_SCREEN) + GRAPH_BUFFER_SCREEN);

  screen.stroke(WHITE_COLOR);
  screen.setTextSize(1);
  screen.text("PM2.5", screen_width - 40, 10);
  screen.text("50 divs", 1, 1);
  screen.text("5 mins", screen_width - 40, screen_height - 10);
  for (size_t i = 0; i < (y_dots / 2) + 1; i++)
    screen.line(GRAPH_BUFFER_SCREEN, screen_height - (2 * i * GRAPH_BUFFER_SCREEN) - GRAPH_BUFFER_SCREEN, GRAPH_BUFFER_SCREEN / 2, screen_height - (2 * i * GRAPH_BUFFER_SCREEN) - GRAPH_BUFFER_SCREEN);
  for (size_t i = 0; i < (x_dots / 2); i++)
    screen.line((2 * i * GRAPH_BUFFER_SCREEN) + GRAPH_BUFFER_SCREEN, screen_height - GRAPH_BUFFER_SCREEN, (2 * i * GRAPH_BUFFER_SCREEN) + GRAPH_BUFFER_SCREEN, screen_height - (GRAPH_BUFFER_SCREEN / 2));
}

/**
 * @brief Plots the graph bars corresponding to value of PM 2.5 after drawing the graph background
 */
void plot_graph_bar(void)
{
  draw_graph_screen();
  change_screen_flag = false;
  Serial.println("Plot Graph");
  last_millis = millis();
  int x_levels = ((screen_width - (2 * GRAPH_BUFFER_SCREEN)) / GRAPH_BUFFER_SCREEN) / 2;
  int y_levels = ((screen_height - (2 * GRAPH_BUFFER_SCREEN)) / (GRAPH_BUFFER_SCREEN * 2));
  int last_graph_position = 0;
  uint16_t registered_level = 0;
  float graph_divisions = 100;
  float scaling_factor = screen_height / (y_levels * graph_divisions);
  screen.stroke(BLACK_COLOR);

  int x_last_pos, y_last_pos;

  while (last_graph_position <= x_levels)
  {
    if (last_graph_position == x_levels)
    {
      draw_graph_screen();
      last_graph_position = 0;
    }

    if ((digitalRead(INT_PIN) == LOW) || change_screen_flag)
    {
      change_screen();
      break;
    }

    registered_level = 0;
    collect_dust_quality_data();
    registered_level = atoi(pm_ae_2_5);

    if ((((millis() - last_millis) > GRAPH_PLOT_TIME) || (last_graph_position == 0)) && (registered_level > 10))
    {
      Serial.println("PM AE 2.5: " + (String)registered_level);
      // Calculating Bar Values
      int scaled_value = 0;
      int height = 0;
      if (registered_level < MAX_HAZARDOUS_LIMIT)
      {
        scaled_value = registered_level * scaling_factor;
        height = scaled_value;
      }
      else
      {
        scaled_value = screen_height - (2 * GRAPH_BUFFER_SCREEN);
        height = screen_height - (2 * GRAPH_BUFFER_SCREEN);
      }
      int x_pos = GRAPH_BUFFER_SCREEN + (2 * GRAPH_BUFFER_SCREEN * last_graph_position) + 1;
      int y_pos = screen_height - GRAPH_BUFFER_SCREEN - scaled_value;
      int width = (2 * GRAPH_BUFFER_SCREEN) - 1;

      if (registered_level < MAX_SAFETY_LIMIT)
        screen.fill(GREEN_COLOR);
      else if (registered_level < MAX_WARNING_LIMIT)
        screen.fill(YELLOW_COLOR);
      else if (registered_level < MAX_UNHEALTHY_LIMIT)
        screen.fill(ORANGE_COLOR);
      else
        screen.fill(RED_COLOR);
      screen.stroke(BLACK_COLOR);
      screen.rect(x_pos, y_pos, width, height);

      if (last_graph_position == 0)
      {
        x_last_pos = x_pos + (width / 2);
        y_last_pos = y_pos;
      }
      else
      {
        x_pos = x_pos + (width / 2);
        screen.fill(WHITE_COLOR);
        screen.stroke(WHITE_COLOR);
        screen.circle(x_last_pos, y_last_pos, 2);
        screen.circle(x_pos, y_pos, 2);
        screen.line(x_last_pos, y_last_pos, x_pos, y_pos);
        x_last_pos = x_pos;
        y_last_pos = y_pos;
      }

      last_millis = millis();
      last_graph_position++;
    }
  }
}

void put_device_to_sleep(void)
{
  Serial.println("Entering Sleep mode");
  screen.fill(GREY_COLOR);
  screen.rect(10, (screen_height / 2) - 40, screen_width - 20, 80);
  screen.fill(BLACK_COLOR);
  screen.stroke(BLACK_COLOR);
  screen.setTextSize(1);
  screen.text("SHUTTING DOWN", 30, (screen_height / 2));
  delay(2000);
  boot_screen();
  screen_counter = 0;
  change_screen_flag = false;
  shutdown_device_peripherals();
  cli();
  set_sleep_mode(SLEEP_MODE_PWR_DOWN);
  cli();
  sleep_enable();
  cli();
  Serial.println("Placing Device in sleep mode");
  Serial.flush();
  delay(2000);
  cli();
  attachInterrupt(digitalPinToInterrupt(INT_PIN), change_screen, LOW);
  cli();
  interrupts();
  sleep_cpu();
}

void changing_screen_display(void)
{
  screen.fill(GREY_COLOR);
  screen.rect(10, (screen_height / 2) - 40, screen_width - 20, 80);
  screen.fill(BLACK_COLOR);
  screen.stroke(BLACK_COLOR);
  screen.setTextSize(1);
  screen.text("CHANGING SCREEN", 20, (screen_height / 2));
}

void change_screen(void)
{
  sleep_disable();
  detachInterrupt(digitalPinToInterrupt(INT_PIN));
  Serial.println("Button pressed");
  delay(500);

  change_screen_flag = true;
  uint64_t sleep_timer = millis();
  while (digitalRead(INT_PIN) == LOW)
    if ((millis() - sleep_timer) > 2000)
    {
      screen_counter = 4;
      return;
    }

  if (screen_counter < 3)
    screen_counter++;
  else
    screen_counter = 1;
  return;
}

void start_device_peripherals(void)
{
  Serial.println("Starting Device Peripherals");
  digitalWrite(PMS_CTRL, HIGH);
  digitalWrite(TFT_DISPLAY_LED, HIGH);
  screen.begin();
  screen.setRotation(180);
  screen_height = screen.height();
  screen_width = screen.width();
  screen.background(BLACK_COLOR);
  screen.stroke(WHITE_COLOR);
  boot_screen();
}

void shutdown_device_peripherals(void)
{
  digitalWrite(PMS_CTRL, LOW);
  digitalWrite(TFT_DISPLAY_LED, LOW);
  Serial.println("Stopping Device Peripherals");
}

//!==================================================================================//

void setup()
{
  Serial.begin(9600);
  Serial.println("\n\n\n----------------------------------------------------------------------------------------");
  Serial.println("Starting Device");
  setup_sensors();
  setup_peripheral_pin_mode();
  start_device_peripherals();
  Serial.println("Setup Done");
  start_device_peripherals();
}

void loop()
{
  changing_screen_display();
  switch (screen_counter)
  {
  case 1:
    Serial.println("\n----------------------------------------------------------------------------------------");
    graphic_data_screen();
    break;

  case 2:
    Serial.println("\n----------------------------------------------------------------------------------------");
    three_point_data_screen();
    break;

  case 3:
    Serial.println("\n----------------------------------------------------------------------------------------");
    plot_graph_bar();
    break;

  case 4:
    Serial.println("\n----------------------------------------------------------------------------------------");
    put_device_to_sleep();
    break;
  }
}

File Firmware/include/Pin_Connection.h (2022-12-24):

/**
 * @file PIN_CONNECTION.h
 * @author Parth Patel (parth.pmech@gmail.com)
 * @brief Check the Pin Connection on this page as per the connection
 * @version 0.1
 * @date 2021-12-27
 * @copyright Copyright (c) 2021
 * ! DO NOT CHANGE
 */

#ifndef PIN_CONNECTION_H
#define PIN_CONNECTION_H

// GPIO PINS
#define NANO_GPIO_2 2
#define NANO_GPIO_3 3
#define NANO_GPIO_4 4
#define NANO_GPIO_5 5
#define NANO_GPIO_6 6
#define NANO_GPIO_7 7
#define NANO_GPIO_8 8
#define NANO_GPIO_9 9
#define NANO_GPIO_10 10
#define NANO_AI_0 A0
#define NANO_AI_1 A1
#define NANO_AI_2 A2
#define NANO_AI_3 A3
#define NANO_AI_6 A6
#define NANO_AI_7 A7

// COMMUNICATION PINS
#define SERIAL_TX 0
#define SERIAL_RX 1
#define SPI_MOSI 11
#define SPI_MISO 12
#define SPI_SCK 13
#define I2C_SDA A4
#define I2C_SCL A5

//!============================== INTERRUPT CONNECTION ==============================//
#define INT_PIN NANO_GPIO_2 // Push Button to change the screens
//!==================================================================================//

//!================================= PMS CONNECTION =================================//
#define PMS_RX NANO_GPIO_7   // Serial RX Pin for the PMS Sensor
#define PMS_TX NANO_GPIO_6   // Serial TX Pin for the PMS Sensor
#define PMS_CTRL NANO_GPIO_5 // Control Pin for the PMS Sensor
//!==================================================================================//

//!=============================== SUPPLY CONNECTION =================================//
#define BATTERY_INPUT NANO_AI_0        // Battery connection input to the Arduino to read the battery level
#define CONNECTED_SUPPLY_PIN NANO_AI_1 // Suppply connection input to the Arduino to read the Charger connection state
//!==================================================================================//

//!============================= DISPLAY CONNECTION =======================================//
#define TFT_DISPLAY_CS NANO_GPIO_10
#define TFT_DISPLAY_DC NANO_GPIO_9
#define TFT_DISPLAY_RST NANO_GPIO_8
#define TFT_DISPLAY_LED NANO_GPIO_4
//!=======================================================================================//

void setup_peripheral_pin_mode(void)
{
    pinMode(PMS_CTRL, OUTPUT);
    pinMode(TFT_DISPLAY_LED, OUTPUT);
    pinMode(INT_PIN, INPUT);
    pinMode(CONNECTED_SUPPLY_PIN, INPUT);
    pinMode(BATTERY_INPUT, INPUT);
}

#endif

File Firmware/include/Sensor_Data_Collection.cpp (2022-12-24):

#ifndef Sensor_Data_Collection_cpp
#define Sensor_Data_Collection_cpp

#include "Arduino.h"
#include "Pin_Connection.h"
#include "Variable_Declaration.h"

// #define HTU21D_TEMP_HUMIDITY_SENSOR
// #define MHZ19C_CO2_SENSOR
// #define TSL2561_LUX_SENSOR
#define PMS_DUST_SENSOR

/* -------------------------------------------------------------------------- */
/*                              BASIC DEFINITION                              */
/* -------------------------------------------------------------------------- */
#ifdef HTU21D_TEMP_HUMIDITY_SENSOR
#include <Wire.h>
#include "HTU21D.h"
HTU21D temperature_and_humidity_sensor; // Create an instance of the object
#endif

#ifdef MHZ19C_CO2_SENSOR
#include "MHZ19.h"
#include "HardwareSerial.h"
HardwareSerial MHZ19CSerial(2);
MHZ19 carbondioxide_sensor; // Constructor for library
#endif

#ifdef TSL2561_LUX_SENSOR
#include <Wire.h>
#include <SparkFunTSL2561.h>
SFE_TSL2561 light_sensor; // Create an SFE_TSL2561 object
// Global variables:
boolean gain;    // Gain setting, 0 = X1, 1 = X16;
unsigned int ms; // Integration ("shutter") time in milliseconds
#endif

#ifdef PMS_DUST_SENSOR
#include <PMS.h>
#include "SoftwareSerial.h"
SoftwareSerial PMSerial2(PMS_RX, PMS_TX);
PMS pms(PMSerial2);
PMS::DATA data;
#define VALUE_LENGTH 5
#define MINIMUM_WIDTH 1
#define NUM_AFTER_DECIMAL 0
char pm_sp_1_0[VALUE_LENGTH], pm_sp_2_5[VALUE_LENGTH], pm_sp_10_0[VALUE_LENGTH]; // Variable to store standard atmospheric particles values
char pm_ae_1_0[VALUE_LENGTH], pm_ae_2_5[VALUE_LENGTH], pm_ae_10_0[VALUE_LENGTH]; // Variable to store Atmospheric environment values
#endif

/* -------------------------------------------------------------------------- */
/*                             FUNCTION DEFINITION                            */
/* -------------------------------------------------------------------------- */
void setup_sensors(void)
{
    Serial.println("Setting up Sensors");
#ifdef HTU21D_TEMP_HUMIDITY_SENSOR
    Serial.println("Setting up Temperature and Humidity Sensor");
    temperature_and_humidity_sensor.begin();
#endif

#ifdef MHZ19C_CO2_SENSOR
    Serial.println("Setting up CO2 Sensor");
    MHZ19CSerial.begin(9600);
    carbondioxide_sensor.begin(MHZ19CSerial);
    carbondioxide_sensor.autoCalibration();
#endif

#ifdef TSL2561_LUX_SENSOR
    Serial.println("Setting up Lux Sensor");
    // Initialize the SFE_TSL2561 library
    // You can pass nothing to light.begin() for the default I2C address (0x39),
    // or use one of the following presets if you have changed
    // the ADDR jumper on the board:
    // TSL2561_ADDR_0 address with '0' shorted on board (0x29)
    // TSL2561_ADDR   default address (0x39)
    // TSL2561_ADDR_1 address with '1' shorted on board (0x49)
    light_sensor.begin();
    // The light sensor has a default integration time of 402ms,
    // and a default gain of low (1X).
    // If you would like to change either of these, you can
    // do so using the setTiming() command.
    // If gain = false (0), device is set to low gain (1X)
    // If gain = high (1), device is set to high gain (16X)
    gain = 0;
    // If time = 0, integration will be 13.7ms
    // If time = 1, integration will be 101ms
    // If time = 2, integration will be 402ms
    // If time = 3, use manual start / stop to perform your own integration
    unsigned char time = 2;
    // setTiming() will set the third parameter (ms) to the requested integration time in ms (this will be useful later):
    Serial.println("Set timing...");
    light_sensor.setTiming(gain, time, ms);
    Serial.println("Powerup..."); // To start taking measurements, power up the sensor
    light_sensor.setPowerUp();
#endif

#ifdef PMS_DUST_SENSOR
    PMSerial2.begin(9600);
#endif
}

#ifdef HTU21D_TEMP_HUMIDITY_SENSOR
String collect_temperature_and_humidity_values(void)
{
    Serial.println("Reading HTU21D");
    uint8_t humd = temperature_and_humidity_sensor.readHumidity();
    uint8_t temp = temperature_and_humidity_sensor.readTemperature();
    Serial.println("Temperature: " + (String)temp + "C");
    Serial.println("Humidity: " + (String)humd + "%");
    return (",T:" + (String)temp + ",H:" + (String)humd);
}
#endif

#ifdef MHZ19C_CO2_SENSOR
String collect_co2_values(void)
{
    Serial.println("Reading MHZ19C");
    uint16_t CO2 = carbondioxide_sensor.getCO2();
    Serial.println("CO2: " + (String)CO2 + "ppm");
    return (",C:" + (String)CO2);
}
#endif

#ifdef TSL2561_LUX_SENSOR
String collect_lux_values(void)
{
    Serial.println("Reading TSL2561");
    double lux;
    unsigned int data0, data1;
    if (light_sensor.getData(data0, data1)) // getData() returned true, communication was successful
    {
        Serial.print("data0: ");
        Serial.print(data0);
        Serial.print(" data1: ");
        Serial.println(data1);
        boolean good;                                            // True if neither sensor is saturated
        good = light_sensor.getLux(gain, ms, data0, data1, lux); // Perform lux calculation:
        Serial.print("Lux: " + (String)lux);                     // Print out the results:
        if (good)
            Serial.println(" | GOOD");
        else
            Serial.println(" | BAD");
    }
    return (",L:" + (String)lux);
}
#endif

#ifdef PMS_DUST_SENSOR
void collect_dust_quality_data(void)
{
    memset(pm_ae_1_0, 0, VALUE_LENGTH);
    memset(pm_ae_2_5, 0, VALUE_LENGTH);
    memset(pm_ae_10_0, 0, VALUE_LENGTH);
    uint32_t timer = millis();
    while (!pms.read(data) && ((millis() - timer) < 2000))
        if (digitalRead(INT_PIN) == LOW)
            break;
    dtostrf(data.PM_AE_UG_1_0, MINIMUM_WIDTH, NUM_AFTER_DECIMAL, pm_ae_1_0);
    dtostrf(data.PM_AE_UG_2_5, MINIMUM_WIDTH, NUM_AFTER_DECIMAL, pm_ae_2_5);
    dtostrf(data.PM_AE_UG_10_0, MINIMUM_WIDTH, NUM_AFTER_DECIMAL, pm_ae_10_0);
}
#endif

#endif

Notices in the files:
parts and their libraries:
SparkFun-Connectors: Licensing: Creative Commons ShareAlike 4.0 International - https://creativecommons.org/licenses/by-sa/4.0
